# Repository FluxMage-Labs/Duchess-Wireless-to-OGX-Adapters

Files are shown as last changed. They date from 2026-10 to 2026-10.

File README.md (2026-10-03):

# Duchess-Wireless-to-OGX-Adapters
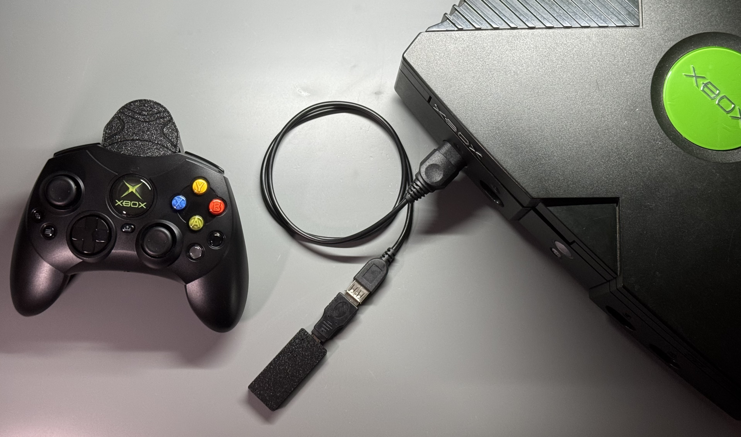
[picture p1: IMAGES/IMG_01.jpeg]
DuchesS Wireless adapters with the original Xbox


These adapters convert the wired-only modern controller, The Hyperkin DuchesS, into a wireless controller for the Original Xbox. Hyperkin made this controller to look and feel like the original S controller from Microsoft. The DuchesS uses hall effect sticks and (thankfully) a detachable USB-C cable. It was designed by Hyperkin to only work on modern Xbox consoles and PC. So, I designed these adapters to use it wirelessly on the OG Xbox. This project is non-destructive, keeping the DuchesS controller in its stock form. The intent is for this to be a fun, DIY, open source project.

The adapters are:

Transmitter – converts USB to Bluetooth, attached to the DuchesS controller.

Receiver – converts Bluetooth to USB, connected to the OG Xbox controller port.

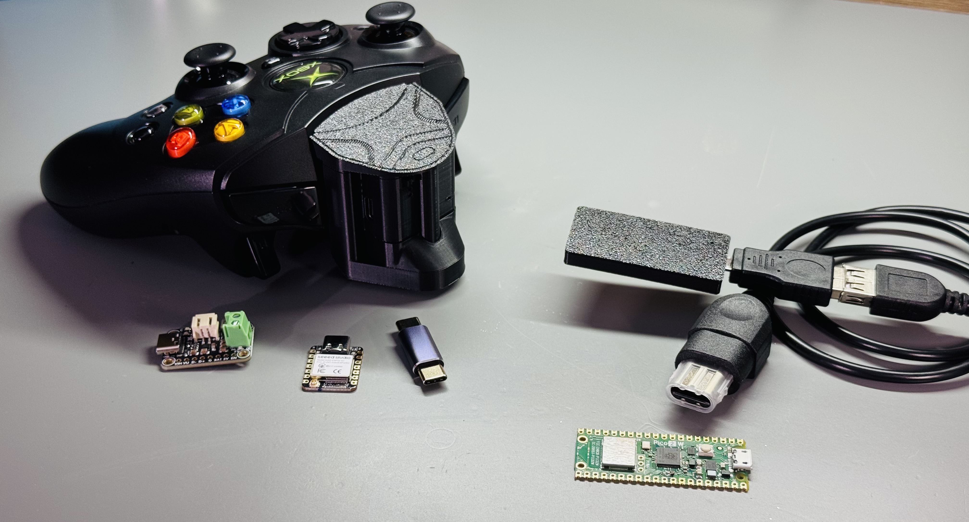
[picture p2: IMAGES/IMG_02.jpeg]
Transmitter and receiver parts


<ins>Please consider the following:</ins>

\*I am sharing this project under the following licenses:

Firmware: GPLv3 License - <https://www.gnu.org/licenses/gpl-3.0.txt>

CAD Designs: CERN-OHL-S-2.0 - <https://ohwr.org/cern_ohl_s_v2.txt>

\*The code for this project was fully vibe-coded with Claude Code using Opus 4.8 during prototyping which produced a working build nearly identical to final v1.0 public release. As of v1.0 the source code was cleaned up and finalized for public release using Opus 5.5 (core functionality was all Opus 4.8, for those who care to know that lol).

\*The enclosures are original designs by me using FreeCAD.

\*As of version 1.0, this project only works properly between the transmitter and receiver.

**These adapters do not currently work with other Bluetooth devices. The transmitter uses Bluetooth LE and thus will not connect to Bluetooth Classic dongles. Also, I can connect the Transmitter to my computer, but the controller inputs don’t work properly. It is coded to work with the OG Xbox receiver only.**

<ins>Below you’ll find:</ins>

1. Video Tutorial
2. Parts List
3. Links to Purchase the parts
4. Wiring Diagram
5. Flashing the Firmware instructions
6. Troubleshooting / Notes

<br>

Please watch the video I made below showing off this project. I explain things in the video that will help anyone considering building this project for themselves.

### [https://youtu.be/EDyjO3ojt0k](https://youtu.be/EDyjO3ojt0k)

<br><br>

Parts require purchase from both Mouser and Amazon. Mouser doesn’t sell everything needed. First look through the parts list, then see links attached below for where to buy each item.

<ins>Parts List:</ins>

- Seeed Studio XIAO ESP32-S3 module – microcontroller board for the Transmitter
- Adafruit Bq25185 (Part # 6106) 5V boost version – Charger and boost circuit for Transmitter
- GCT Slide Switch (MFG Part # SWS065-030V12TSK) – On/Off switch for Transmitter
- 803040 Lipo battery 3.7V 1000mAh with JST PH 2.0mm connector – Transmitter battery
- USB-C Male to Male adapter (32.5mm length) – More of an extender/coupler than an adapter\
  **(The length is important here. Anything less than 32mm won’t fit with the current enclosure).**
- Raspberry Pi Pico 2W – microcontroller board for the Receiver
- USB A Male to USB Micro Male adapter – Converts the Pico’s micro USB to Type A USB
- USB A Female to OG Xbox controller port adapter – Converts USB A to Xbox controller input

\*You’ll also need wires, solder, heat shrink tubing if reversing polarity on the battery (you’ll likely need to do this, the video explains why).

I used 28 AWG stranded wire, but anything similar will work.

\*For the enclosures, I use basic PLA filament.

\*For flashing the firmware, I use a USB Micro to USB-A cable for the Pico, and a USB-C to USB-A cable for the ESP32S3. 

<br>

<ins>-Links to purchase-</ins>

**Mouser project link:** <https://www.mouser.com/en/Tools/Project/Share?AccessID=2832383652>

above link contains the seeed studio ESP32-S3, Adafruit Bq25185, GCT slide switch, Pi Pico 2W.

**Amazon links:** (multiple options in case one goes out of stock, non-affiliate links)

803040 Lipo battery with JST PH 2.0mm connectors -

<https://a.co/d/0bvvcZND>

-or-

<https://a.co/d/07NkPaJw>

USB-C Male to Male adapter 32.5mm total length -

<https://a.co/d/045cscGm>

-or-

<https://a.co/d/06tyFEHX>

USB-A Male to USB Micro Male adapter -

<https://a.co/d/08DQSm7P>

USB-A Female to OG Xbox controller port adapter -

<https://a.co/d/07X1W7fQ>

-or-

<https://a.co/d/00STg7iH>

<br>

<ins>Wiring Diagram:</ins>

(Notice the polarity of the battery had to be switched to match the charger board!)

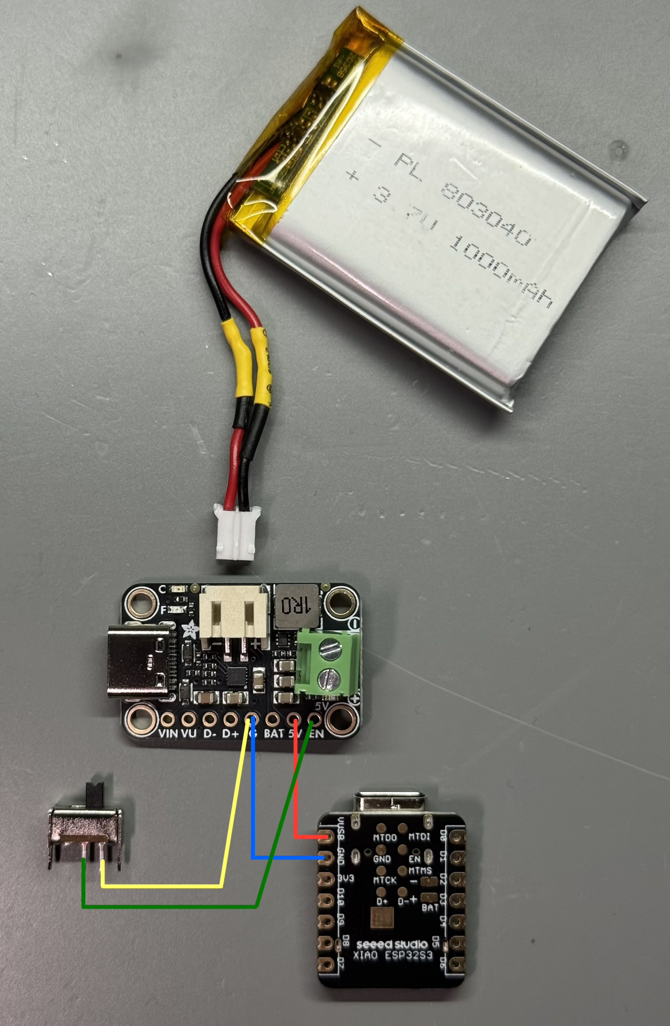
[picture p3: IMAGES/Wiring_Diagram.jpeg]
Wiring diagram


\*Instructions for installing the hardware into the Transmitter enclosure are in the video. 

<br>

<ins>Flashing the Firmware:</ins>

**Transmitter -**

- Download the latest ‘TX_v1.x_merged.bin’ file from the [Releases page](https://github.com/FluxMage-Labs/Duchess-Wireless-to-OGX-Adapters/releases/latest)
- Plug in a USB cable into your computer
- Hold down the “B” (Boot) button on the ESP32S3
- Plug in the other end of the USB cable into the USB-C port of the ESP32S3
- Then release the “B” button on the ESP32S3
- Navigate to the following URL in a Chromium based browser:\
  <https://esptool.spacehuhn.com>
- Click “Connect”
- A Pop-up should appear where you can choose your ESP32S3
- Select it and click “connect” in that pop-up window
- The pop-up window should close
- If a previous firmware already exists, choose “erase” and continue
- Next click the “reset” option on the bottom left of the list on screen\
  (If this is your first time, reset might not do anything, that’s fine. You should see 4 rows listed.)
- Delete rows 2, 3, and 4
- In row 1, delete “1000” and change it to “0”\
  (This starts the binary at 0x0 which is where the merged binary file is designed to start.)
- Click “select” and choose the “...merged.bin” file you downloaded
- Click “Program”
- You should see the Output reads “Done!” and then a message to reset your device (ignore the reset)
- Unplug the ESP32S3 from your computer
- Finished.

**Receiver -**

- Download the latest ‘RX_v1.x_firmware.uf2’ file from the [Releases page](https://github.com/FluxMage-Labs/Duchess-Wireless-to-OGX-Adapters/releases/latest)
- Plug in a USB cable into your computer
- Hold down the BOOTSEL button on the Pi Pico 2W
- Plug in the other end of the USB cable into the USB Micro port of the Pico
- Then release the BOOTSEL button
- Your Pico should show up on your computer similar to a flash drive
- Drag and drop the latest ‘...firmware.uf2’ file into the root directory of the Pico
- The Pico should immediately auto-eject itself from your computer
- Unplug the Pico from your computer
- Finished.

<br>

<ins>Troubleshooting / Notes:</ins>

\* If the transmitter pairs with the receiver, but the Xbox is not receiving controller inputs. **First, make sure the battery is fully charged.** Also, try unplugging the Transmitter from the DuchesS, flipping the orientation of the USB-C to USB-C adapter (from top to bottom) then reconnect the Transmitter to the DuchesS making sure there is a solid tight connection. Then try connecting again. If that doesn’t work, then try flipping the orientation of the adapter (swapped from which side plugs into the controller and Transmitter). We’re trying to change the path that power is flowing through the little adapter to rule that out. **If the DuchesS doesn’t have a good power connection, you can see a faint, slow flicker on the white LED of the DuchesS controller.** If this doesn’t fix the problem, it could potentially be an issue with the solder connections. The DuchesS needs reliable power to function properly.

\* I wouldn’t recommend using less than a 1000mAh battery. Yes, you can avoid having to reverse the polarity on the battery if you buy a battery from Adafruit. I have not tested this project with less than 1000mAh and I’m confident that on a normal controller, you can get away with less capacity, but on this project, for everything to work properly and last long enough through a gaming session or two, you’ll want to keep the battery charged up and not get low enough that it drops out on you.

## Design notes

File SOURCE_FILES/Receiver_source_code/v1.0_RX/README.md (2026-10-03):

# DuchesS Wireless — Receiver (Pi Pico 2 W)

**Version:** v1.0

BLE-to-OG-Xbox bridge firmware for the **Raspberry Pi Pico 2 W**.

Receives wireless BLE gamepad data from the DuchesS Wireless transmitter
(XIAO ESP32S3) and presents it to the **Original Xbox** as a wired
Controller S using the Xbox's XID USB protocol.

This folder is the **receiver** half. The transmitter firmware is in the
[`transmitter/`](../transmitter) folder of this repository. Use the v1.0
transmitter with the v1.0 receiver.

## Signal Chain

```
DuchesS controller (USB/GIP)
    ↓  wired USB
XIAO ESP32S3 (transmitter - BLE gamepad peripheral)
    ↓  wireless BLE
Pi Pico 2 W (THIS FIRMWARE - BLE central + USB XID device)
    ↓  USB via Xbox-to-USB adapter cable
Original Xbox controller port
```

## Hardware Required

| Component | Purpose |
|---|---|
| Raspberry Pi Pico 2 W | Receiver board (BLE + USB) |
| Xbox-to-USB adapter cable | Converts the Xbox controller plug to USB |
| XIAO ESP32S3 + DuchesS | The transmitter side (separate firmware) |
| USB-UART adapter (optional) | For debug serial output on GP0/GP1 |

## Building

Tested with **Pico SDK 2.2.0** and **Arm GNU Toolchain 14.2** (GCC 14.2.1).
The target board (`pico2_w`) is already set in `CMakeLists.txt`.

### Option 1: Linux command line

1. Install the build tools:

   - Arch / EndeavourOS / Manjaro:
     ```bash
     sudo pacman -S --needed base-devel git cmake ninja python arm-none-eabi-gcc arm-none-eabi-newlib
     ```
   - Debian / Ubuntu / Raspberry Pi OS:
     ```bash
     sudo apt install build-essential git cmake ninja-build python3 gcc-arm-none-eabi libnewlib-arm-none-eabi libstdc++-arm-none-eabi-newlib
     ```

2. Get the Pico SDK 2.2.0 **with its submodules** (BTstack, the CYW43
   wireless driver and TinyUSB live in submodules — the build fails
   without them):
   ```bash
   git clone -b 2.2.0 https://github.com/raspberrypi/pico-sdk.git ~/pico-sdk
   cd ~/pico-sdk
   git submodule update --init
   ```

3. Build, from this `receiver` folder:
   ```bash
   export PICO_SDK_PATH=~/pico-sdk
   cmake -B build -G Ninja
   cmake --build build
   ```
   Instead of the `export`, you can pass the path directly:
   `cmake -B build -G Ninja -DPICO_SDK_PATH=$HOME/pico-sdk`

   The first configure downloads and builds `picotool` (a Raspberry Pi
   helper tool), so it needs an internet connection and takes a little
   longer.

4. The firmware is `build/duchess_receiver.uf2`.

### Option 2: VS Code with the Raspberry Pi Pico extension (Windows, macOS, Linux)

1. Install the **Raspberry Pi Pico** extension. It downloads the SDK,
   toolchain, CMake and Ninja for you.
2. Use **Import Project** on this `receiver` folder and choose **SDK 2.2.0**.
3. Click **Compile**. The output is `build/duchess_receiver.uf2`.

## Flashing

The Pico 2 W uses drag-and-drop flashing — no programmer needed.

1. **Hold the BOOTSEL button** on the Pico 2 W
2. While holding it, **plug the Pico into your computer via micro-USB**
3. Release BOOTSEL — the Pico appears as a USB drive named **RP2350**
4. **Copy `duchess_receiver.uf2` onto that drive**
5. The Pico reboots automatically and starts running the firmware

Pre-built `.uf2` files are attached to the project's GitHub Releases.

## Usage

### First Time Setup

1. Flash the receiver firmware onto the Pico 2 W (see above)
2. Flash the transmitter firmware onto the XIAO ESP32S3 (see `transmitter/`)
3. Power on the XIAO with the DuchesS controller connected
4. Connect the Pico 2 W to the OG Xbox via the Xbox-to-USB adapter cable
5. The Pico scans for and connects to the transmitter automatically
6. Once connected, the Xbox sees a controller

### Normal Operation

1. Plug the Pico 2 W into the Xbox (via the adapter cable) — it immediately
   appears as a Controller S to the Xbox
2. Power on the XIAO transmitter with the DuchesS controller
3. The Pico auto-connects via BLE within a few seconds
4. Play!

### Re-pairing / Troubleshooting BLE

Pairing is automatic. Both the receiver and the transmitter clear their
stored BLE pairing data every time they power up, so if the connection ever
gets stuck (for example after reflashing either side), **power-cycle both
the transmitter and the receiver** and they will pair again from scratch.

If everything lights up but no inputs reach the Xbox, check the
transmitter's battery first — see the Troubleshooting section in the
transmitter README.

## LED Indicators

| Pattern | Meaning |
|---|---|
| Fast blink (5 Hz) | Scanning for the transmitter |
| Slow blink (1 Hz) | BLE connected, Xbox USB not yet active |
| Solid ON | Both BLE and Xbox USB active — ready to play |

## Button Mapping (DuchesS → OG Xbox)

| DuchesS | OG Xbox |
|---|---|
| A | A (analog 0xFF) |
| B | B (analog 0xFF) |
| X | X (analog 0xFF) |
| Y | Y (analog 0xFF) |
| White / LB (Left Bumper) | White (analog 0xFF) |
| Black / RB (Right Bumper) | Black (analog 0xFF) |
| Start / Menu | Start |
| Back / View | Back |
| Left Stick Click | Left Stick Click |
| Right Stick Click | Right Stick Click |
| D-Pad | D-Pad |
| Left Stick | Left Stick |
| Right Stick | Right Stick |
| Left Trigger | Left Trigger (scaled 0-255) |
| Right Trigger | Right Trigger (scaled 0-255) |

Note: The OG Xbox Controller S has analog (pressure-sensitive) face
buttons. The DuchesS face buttons are digital, so they send either 0x00
(off) or 0xFF (fully pressed).

## Technical Details

### XID Protocol

The OG Xbox uses a USB protocol called XID (Xbox Input Devices):
- Interface class `0x58` ('X'), subclass `0x42` ('B')
- Not standard USB HID — no HID descriptors
- Vendor-specific control transfers for device identification
- 20-byte input reports, 6-byte output reports (rumble)
- Identifies as VID `0x045E` / PID `0x0289` (Controller S), which the
  Xbox requires in order to accept the controller
- USB 1.1 Full Speed, 4 ms polling interval

### BLE Connection

The receiver acts as a BLE Central (client):
- Scans for a device named exactly "DuchesS Wireless"
- Connects with Just Works pairing + bonding
- Discovers the HID service (UUID 0x1812)
- Subscribes to input report notifications (15-byte reports: buttons,
  six axes, then the hat switch as the last byte)
- Auto-reconnects on disconnection

The transmitter requests a 7.5–8.75 ms BLE connection interval for low
latency.

### Latency Budget (estimated)

| Stage | Latency |
|---|---|
| DuchesS → XIAO GIP read | ~1-2 ms |
| XIAO BLE notification queue | ~0.5 ms |
| BLE connection interval | 0-8.75 ms |
| BLE air time + processing | ~0.5-1 ms |
| Pico mapping + XID buffer | ~0.1 ms |
| Xbox USB poll | 0-4 ms (avg 2 ms) |
| **Total end-to-end** | **~5-15 ms typical** |

## Project Structure

```
receiver/
├── CMakeLists.txt              # Build configuration
├── pico_sdk_import.cmake       # Locates the Pico SDK (from Raspberry Pi)
├── README.md                   # This file
├── LICENSE-EXCEPTION.md        # GPLv3 section 7 additional permission
└── src/
    ├── btstack_config.h        # BTstack configuration
    ├── tusb_config.h           # TinyUSB configuration
    ├── gamepad_state.h/.c      # Shared gamepad state
    ├── ble_hid_client.h/.c     # BLE Central HID client
    ├── xid_device.h/.c         # OG Xbox XID USB device
    └── main.c                  # Entry point, ties everything together
```

## Debug Output

Connect a USB-UART adapter to the Pico's UART0 pins:
- **GP0** (Pin 1) = TX → connect to adapter's RX
- **GP1** (Pin 2) = RX → connect to adapter's TX (optional)
- **GND** → connect to adapter's GND

Open a serial terminal at **115200 baud** to see debug output.

## License

GNU GPL v3 or later — see the LICENSE file at the repository root —
**with an additional permission** under GPLv3 section 7 that allows
combining this firmware with BTstack and the CYW43 wireless driver from the
Raspberry Pi Pico SDK. See [LICENSE-EXCEPTION.md](LICENSE-EXCEPTION.md).
Each source file carries an `SPDX-License-Identifier: GPL-3.0-or-later`
header and a pointer to that exception.

## Third-party components

None of these are included in this folder; they come with the Pico SDK
when you build.

- **Raspberry Pi Pico SDK** — BSD-3-Clause.
  `pico_sdk_import.cmake` in this folder is Raspberry Pi's standard helper
  file, included unmodified with its BSD-3-Clause notice.
- **TinyUSB** — MIT License.
- **BTstack** by BlueKitchen GmbH — BlueKitchen license (non-commercial),
  plus Raspberry Pi's license for use on Raspberry Pi hardware.
- **cyw43-driver** by George Robotics (with the Infineon CYW43439 firmware)
  — George Robotics license (non-commercial) in the version used by SDK
  2.2.0, plus Raspberry Pi's license for use on Raspberry Pi hardware.

## Credits

- [xboxdevwiki.net](https://xboxdevwiki.net/Xbox_Input_Devices) — XID
  protocol documentation
- [OGX-Mini](https://github.com/wiredopposite/OGX-Mini) — consulted as a
  reference for XID on RP2040/RP2350 (no code from it is used here)
- [BTstack](https://github.com/bluekitchen/btstack),
  [TinyUSB](https://github.com/hathach/tinyusb),
  [Pico SDK](https://github.com/raspberrypi/pico-sdk)

## Disclaimer

This is an independent, non-commercial hobby project. It is not affiliated
with, endorsed by, or sponsored by Microsoft, Hyperkin, or Raspberry Pi.
"Xbox" is a trademark of Microsoft Corporation; "Hyperkin" and "DuchesS"
are trademarks of their respective owner. These names, and the Controller S
USB identifiers the Xbox requires, are used only for compatibility and to
describe what hardware this project works with.

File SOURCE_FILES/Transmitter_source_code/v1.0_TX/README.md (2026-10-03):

# DuchesS Wireless — Transmitter (XIAO ESP32S3)

**Version:** v1.0

Firmware that converts a wired Hyperkin DuchesS USB controller into a
wireless controller for the Original Xbox.

**Signal chain:**

```
DuchesS (USB/GIP) -> XIAO ESP32S3 (this firmware) -> BLE -> Pi Pico 2 W receiver -> OG Xbox
```

This folder is the **transmitter** half. The Pi Pico 2 W **receiver**
firmware is in the [`receiver/`](../receiver) folder of this repository.

## Hardware

- Seeed Studio XIAO ESP32S3
- Hyperkin DuchesS controller, connected via USB-C OTG adapter
- 1-cell LiPo battery + charge/boost board supplying 5V to the XIAO's
  VUSB pin (the XIAO's own USB-C port is occupied by the controller in
  host mode). Reference board: **Adafruit bq25185 USB/DC/Solar Charger
  with 5V Boost** (Adafruit #6106) — battery on the JST port, board
  "+" (5V) output to XIAO VUSB, grounds common.
- Optional: USB-UART adapter on GPIO43(TX)/GPIO44(RX), 115200 baud,
  for debug output

> **Boost converter startup note (bq25185 board):** its TPS61023 boost
> converter can stall into loads that instantly draw more than ~200mA
> at power-up. The ESP32-S3 starts below that and only ramps up when
> the radio and USB host come alive moments later, so normal operation
> is fine — but if you add extra hardware to the 5V rail, keep its
> inrush in mind.

## Low-battery indicator (optional, recommended)

A weak LiPo can light every status LED in the system while still
sagging under the ESP32-S3's radio transmit spikes and the USB host
port's load — the result is "all lights on, but no controller inputs
reach the Xbox." The firmware supports two independent detection
methods. Wire either (or both); each is safely inactive when left
unconnected.

### Method A — battery voltage sense (works with the bq25185 board)

The bq25185 board exposes the raw battery voltage on its bottom-edge
**BAT** pad. Feed it to the XIAO through a divider:

```
BAT pad ──[100kΩ]──●──[100kΩ]── GND
                   │
              XIAO A0 (D0)
```

The divider halves the battery voltage into the ADC's range and draws
only ~21µA. The firmware auto-detects it: after a few seconds of
plausible readings it arms, then reports the live voltage on the debug
UART and warns below 3.30V (recovering above 3.60V). If nothing is
wired to A0, the method never arms and nothing changes.

### Method B — dedicated low-battery pin (LBO-style boards)

If your charge/boost board instead has a low-battery output (often
labeled **LBO**, **LB**, or **LOWBATT** — pulls LOW when the battery is
nearly empty), connect it to the XIAO's **D1 (GPIO2)**. Internal
pull-up; leave unconnected if unused.

## LED status codes

| Pattern | Meaning |
|---|---|
| Triple-blink burst | **LOW BATTERY — charge before use!** |
| Fast blink (5/sec) | Waiting for the DuchesS controller (USB) |
| Slow blink (1/sec) | Controller OK, waiting for the receiver (BLE)  |
| Solid on | Fully connected and operational |

## Troubleshooting

**Everything lights up, but no inputs reach the Xbox.**
Almost always a **weak battery**. A partially charged LiPo has enough
power to light every LED — the charger board, the ESP32, the
controller's white light, even to trigger the receiver's connect
light — while still sagging under load. LEDs prove almost nothing
about available power.

1. Fully charge the battery, or power the XIAO's 5V input from a bench
   supply / USB source to rule power out.
2. Wire the low-battery indicator (above) and the triple-blink pattern
   will tell you directly.

**Controller inputs feel dead after reflashing.**
Power-cycle both the transmitter and the receiver. Both sides clear
their BLE bonds at boot and re-pair automatically.

**Serial port won't connect when flashing (Linux).**
Your user needs permission for the serial device. On Arch-based
distros: `sudo usermod -aG uucp $USER`, then log out and back in.

## Building

See [BUILDING.md](BUILDING.md) for the full build, merge, and flash
procedure, including the exact pinned library versions this firmware
requires.

## License

GNU GPL v3 or later — see the LICENSE file at the repository root —
**with an additional permission** under GPLv3 section 7 that allows
linking with Espressif's precompiled (binary-only) ESP-IDF libraries.
See [LICENSE-EXCEPTION.md](LICENSE-EXCEPTION.md). Each source file
written for this project carries an
`SPDX-License-Identifier: GPL-3.0-or-later` header and a pointer to
that exception.

## Third-party code

- **ESP32-BLE-Gamepad** by lemmingDev — MIT License, vendored in
  [`lib/ESP32-BLE-Gamepad`](lib/ESP32-BLE-Gamepad) with its original
  [`license.txt`](lib/ESP32-BLE-Gamepad/license.txt).
  Source: <https://github.com/lemmingDev/ESP32-BLE-Gamepad>, upstream
  commit `33a3dee` (library version 0.7.4).
  **Modified:** `BleConnectionStatus.cpp` — one line added to
  `onConnect()` (`this->connected = true;`) so the connection is reported
  as soon as the link is up, rather than only after authentication.
- **NimBLE-Arduino** by h2zero — Apache License 2.0. Not included in this
  repository; PlatformIO downloads the pinned version (2.3.9) at build
  time.

## Disclaimer

This is an independent, non-commercial hobby project. It is not
affiliated with, endorsed by, or sponsored by Hyperkin or Microsoft.
"Hyperkin" and "DuchesS" are trademarks of their respective owner, and
"Xbox" is a trademark of Microsoft Corporation. These names are used
only to describe what hardware this project works with.

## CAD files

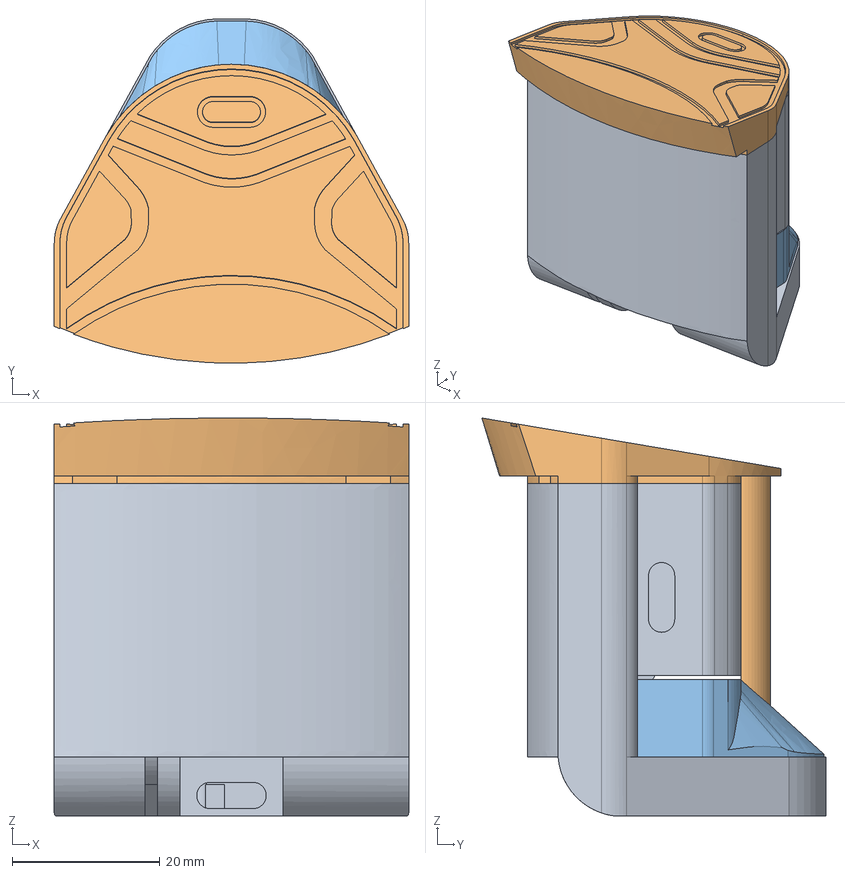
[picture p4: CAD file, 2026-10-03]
SOURCE_FILES/FreeCAD_files/v1.0_Transmitter.FCStd
48.0 x 46.6 x 53.9 mm
Main Body
Top Lid
Bottom Lid

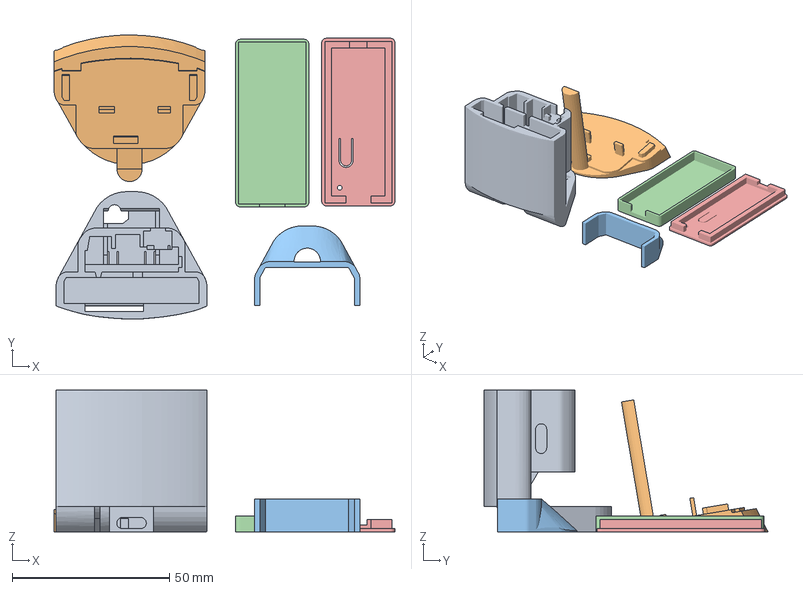
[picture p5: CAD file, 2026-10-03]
v1.0_Enclosures.3mf
108.3 x 90.3 x 45.0 mm

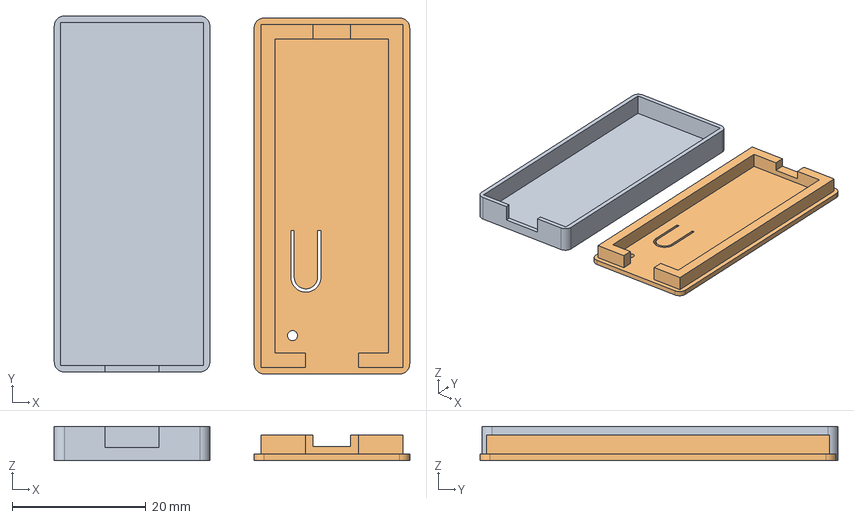
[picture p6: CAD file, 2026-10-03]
SOURCE_FILES/FreeCAD_files/v1.0_Receiver.FCStd
53.2 x 53.6 x 5.10 mm
Lid

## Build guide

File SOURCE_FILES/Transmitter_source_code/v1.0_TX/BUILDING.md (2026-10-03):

# Building the DuchesS Wireless Transmitter (XIAO ESP32S3)

## Requirements
- PlatformIO Core (CLI) 6.x — `pipx install platformio`
- Internet access on first build (downloads espressif32 platform + toolchain)

## Build

From this folder (the one containing `platformio.ini`):

```bash
pio run
```

Artifacts land in `.pio/build/seeed_xiao_esp32s3/`:
`bootloader.bin`, `partitions.bin`, `firmware.bin`.

> If you previously built with different library versions, do a clean
> build first: `rm -rf .pio && pio run`

## Create the single-file merged image (for web flashers)

```bash
cd .pio/build/seeed_xiao_esp32s3

pio pkg exec -p tool-esptoolpy -- esptool.py --chip esp32s3 merge_bin \
  -o merged.bin \
  --flash_mode dio --flash_freq 80m --flash_size 8MB \
  0x0 bootloader.bin \
  0x8000 partitions.bin \
  0xe000 ~/.platformio/packages/framework-arduinoespressif32/tools/partitions/boot_app0.bin \
  0x10000 firmware.bin
```

> **Note:** the `boot_app0.bin` path above assumes PlatformIO's default
> location on Linux/macOS. On Windows use
> `%USERPROFILE%\.platformio\packages\framework-arduinoespressif32\tools\partitions\boot_app0.bin`,
> or wherever your PlatformIO core directory is (`pio system info` shows it).

`merged.bin` flashes as a single file at offset `0x0`.

## Flash (PlatformIO direct)

Hold BOOT on the XIAO, plug it into your computer, release BOOT, then:

```bash
pio run -t upload
```

## Flash (web flasher method)

1. Hold the BOOT button on the XIAO ESP32S3
2. Plug in the USB-C cable, then release BOOT
3. Open a Web-Serial flasher (e.g. esptool.spacehuhn.com) in a
   Chromium-based browser and Connect
4. Single entry: offset `0x0`, file `merged.bin`
5. Erase (recommended), then Program
6. Unplug/replug the XIAO to boot the new firmware

Linux note: your user must be able to open the serial port
(`uucp` group on Arch: `sudo usermod -aG uucp $USER`, then re-login).

## Before publishing binaries

Verify no local paths leaked into the artifacts:

```bash
strings merged.bin | grep -iE '/home/|users' && echo "LEAK FOUND" || echo "clean"
```

## Version pins — do not bump casually

| Component | Version | Why pinned |
|---|---|---|
| espressif32 platform | 6.9.0 | Matches the verified-working release build |
| NimBLE-Arduino | 2.3.9 | Exact version of the verified-working build (verified byte-identical to the official GitHub 2.3.9 tag, so the registry pin is safe). |
| ESP32-BLE-Gamepad | vendored in `lib/` | The registry's "0.7.4" changed content over time WITHOUT a version bump - connection-status semantics and the HID report descriptor were altered, silently breaking pairing/input flow. The exact verified-working source (including a local fix in BleConnectionStatus.cpp) is committed in `lib/ESP32-BLE-Gamepad` and used automatically. Never replace it with a registry copy. |

Do not add ESP32-BLE-Gamepad back to `lib_deps` - the local `lib/` copy
must be the one that builds.

## After flashing: if it doesn't work

See the Troubleshooting section in [README.md](README.md) first —
especially the weak-battery failure mode, which mimics several other
problems. Always do first functional tests on solid power (bench supply
or full battery), never on a partially charged LiPo.

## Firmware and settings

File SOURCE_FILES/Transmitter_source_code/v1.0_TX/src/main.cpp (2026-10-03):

// SPDX-License-Identifier: GPL-3.0-or-later
// Copyright (C) 2026 DuchesS Wireless contributors
// Additional permission under GNU GPL version 3 section 7: see LICENSE-EXCEPTION.md

/*
 * main.cpp - DuchesS Wireless Transmitter
 *
 * XIAO ESP32S3 firmware: reads DuchesS controller via USB Host (GIP)
 * and transmits as BLE HID gamepad to the Pi Pico 2 W receiver.
 *
 * Signal chain:
 *   DuchesS (USB/GIP) -> XIAO ESP32S3 (this) -> BLE -> Pico 2 W -> OG Xbox
 *
 * Hardware:
 *   - Single USB-C port: used for flashing (from PC) then USB Host (controller)
 *   - LED: GPIO21, active LOW
 *   - Debug UART: GPIO43(TX), GPIO44(RX), 115200 baud
 *
 * OPTIONAL LOW-BATTERY DETECTION (two methods, wire either or both;
 * both are safely inactive when left unconnected):
 *
 *   Method A - Analog battery sense on A0 (GPIO1):
 *     For charge/boost boards that expose the raw battery voltage,
 *     e.g. the Adafruit bq25185 5V Boost board's bottom-edge BAT pad.
 *     Wire: BAT pad -> 100k resistor -> A0 -> 100k resistor -> GND.
 *     The divider halves the battery voltage into the ADC's range.
 *     The firmware auto-detects the divider: it arms only after
 *     several consecutive readings in the plausible LiPo range, so an
 *     unwired (floating) pin can never trigger a false warning.
 *
 *   Method B - Digital low-battery input on D1 (GPIO2), active LOW:
 *     For charge/boost boards with a dedicated low-battery output
 *     (often labeled LBO, LB, or LOWBATT, e.g. Adafruit PowerBoost).
 *     The internal pull-up keeps this inactive when unconnected.
 *
 * LED status codes (LED is active LOW):
 *   Triple-blink burst = LOW BATTERY - charge before use!
 *   Fast blink (5/sec) = waiting for USB controller
 *   Slow blink (1/sec) = USB OK, waiting for BLE receiver
 *   Solid ON           = USB + BLE connected, fully operational
 *
 * WHY THE LOW-BATTERY INDICATOR EXISTS:
 *   A weak LiPo can light every status LED in the system (charger,
 *   ESP32, controller, even trigger the receiver's connect light)
 *   while still sagging under the ESP32-S3's radio transmit spikes
 *   and the USB host port's supply load - the result is "all lights
 *   on, but no controller inputs reach the Xbox." The dedicated
 *   triple-blink pattern makes that failure unmistakable.
 */

#include <Arduino.h>
#include "gamepad_state.h"
#include "usb_host_xbox.h"
#include "ble_output.h"

// Debug UART on GPIO43(TX) / GPIO44(RX) since USB port becomes Host
#define DEBUG_TX_PIN 43
#define DEBUG_RX_PIN 44
HardwareSerial DebugSerial(1);

static gamepad_state_t gamepad;

// XIAO ESP32S3 LED: GPIO21, active LOW (LOW = on, HIGH = off)
#define LED_PIN 21

// ---------------------------------------------------------------------------
// Low-battery detection configuration
// ---------------------------------------------------------------------------

// Method A: analog battery sense (XIAO A0). Battery voltage through a
// 100k/100k divider, so measured mV * 2 = battery mV.
#define BATT_SENSE_PIN        1      // GPIO1 = XIAO A0/D0
#define BATT_DIVIDER_RATIO    2      // 100k : 100k divider halves voltage
#define BATT_LOW_MV           3300   // warn below 3.30V
#define BATT_RECOVER_MV       3600   // clear warning above 3.60V
// Plausible single-cell LiPo range; readings outside this mean the
// divider is not wired (floating pin) and the method stays disarmed.
#define BATT_PLAUSIBLE_MIN_MV 2700
#define BATT_PLAUSIBLE_MAX_MV 4400
#define BATT_ARM_SAMPLES      5      // consecutive plausible reads to arm
#define BATT_SAMPLE_MS        1000   // sample interval

// Method B: digital low-battery input (XIAO D1). Active LOW, pull-up.
#define LOW_BATT_PIN     2
#define LOW_BATT_ON_MS   500         // continuously LOW this long -> warn
#define LOW_BATT_OFF_MS  2000        // continuously HIGH this long -> clear

// ---------------------------------------------------------------------------

static uint32_t last_status_print = 0;
static uint32_t last_ble_send     = 0;
static uint32_t last_led_toggle   = 0;
static bool     led_state         = false;

// Method A state
static bool     batt_sense_armed   = false;
static uint8_t  batt_arm_count     = 0;
static bool     batt_analog_low    = false;
static uint32_t batt_last_sample   = 0;
static uint32_t batt_mv            = 0;   // last measured battery voltage

// Method B state
static bool     lbo_active     = false;
static uint32_t lbo_last_high  = 0;
static uint32_t lbo_last_low   = 0;

void setup() {
    DebugSerial.begin(115200, SERIAL_8N1, DEBUG_RX_PIN, DEBUG_TX_PIN);
    delay(500);

    DebugSerial.println("============================================");
    DebugSerial.println("  DuchesS Wireless Transmitter");
    DebugSerial.println("  XIAO ESP32S3 -> BLE -> Pico 2 W -> Xbox");
    DebugSerial.println("  Firmware v1.0");
    DebugSerial.println("============================================");
    DebugSerial.println();

    // LED off initially
    pinMode(LED_PIN, OUTPUT);
    digitalWrite(LED_PIN, HIGH);

    // Method B input: pull-up keeps it inactive when unconnected
    pinMode(LOW_BATT_PIN, INPUT_PULLUP);
    uint32_t boot_ms = millis();
    lbo_last_high = boot_ms;
    lbo_last_low  = boot_ms;

    // Method A input: plain analog pin; auto-arms only if a divider
    // feeding plausible LiPo voltages is detected.
    analogReadResolution(12);

    gamepad_state_reset(&gamepad);

    // Start BLE first (begins advertising immediately)
    ble_output_init();

    // Then start USB Host for the DuchesS controller
    usb_host_xbox_init(&gamepad);

    DebugSerial.println("[MAIN] Setup complete!");
    DebugSerial.println("[MAIN] Connect DuchesS via USB-C OTG adapter");
    DebugSerial.println("[MAIN] Pico 2 W receiver auto-connects via BLE");
    DebugSerial.println();
}

// ---------------------------------------------------------------------------
// Low-battery detection task (both methods)
// ---------------------------------------------------------------------------
static void low_battery_task(uint32_t now) {
    // ---- Method A: analog battery sense ----
    if (now - batt_last_sample >= BATT_SAMPLE_MS) {
        batt_last_sample = now;

        // Calibrated millivolts at the pin; x2 for the 100k/100k divider
        uint32_t pin_mv = analogReadMilliVolts(BATT_SENSE_PIN);
        uint32_t measured_mv = pin_mv * BATT_DIVIDER_RATIO;

        bool plausible = (measured_mv >= BATT_PLAUSIBLE_MIN_MV &&
                          measured_mv <= BATT_PLAUSIBLE_MAX_MV);

        if (!batt_sense_armed) {
            // Require several consecutive plausible readings before
            // trusting the input - a floating pin wanders and will
            // not hold a steady LiPo-range value.
            if (plausible) {
                if (++batt_arm_count >= BATT_ARM_SAMPLES) {
                    batt_sense_armed = true;
                    batt_mv = measured_mv;
                    DebugSerial.printf("[BATT] Battery sense detected on A0 (%lumV)\n",
                                       (unsigned long)measured_mv);
                }
            } else {
                batt_arm_count = 0;
            }
        } else {
            batt_mv = measured_mv;
            if (!batt_analog_low && measured_mv < BATT_LOW_MV) {
                batt_analog_low = true;
                DebugSerial.printf("[BATT] LOW BATTERY (%lumV) - charge before use!\n",
                                   (unsigned long)measured_mv);
            } else if (batt_analog_low && measured_mv > BATT_RECOVER_MV) {
                batt_analog_low = false;
                DebugSerial.printf("[BATT] Battery recovered (%lumV)\n",
                                   (unsigned long)measured_mv);
            }
        }
    }

    // ---- Method B: digital LBO input (active LOW, hysteresis latch) ----
    if (digitalRead(LOW_BATT_PIN) == HIGH) {
        lbo_last_high = now;
    } else {
        lbo_last_low = now;
    }

    if (!lbo_active && (now - lbo_last_high >= LOW_BATT_ON_MS)) {
        lbo_active = true;
        DebugSerial.println("[BATT] LOW BATTERY (LBO pin) - charge before use!");
    } else if (lbo_active && (now - lbo_last_low >= LOW_BATT_OFF_MS)) {
        lbo_active = false;
        DebugSerial.println("[BATT] Battery level OK again (LBO pin)");
    }
}

static inline bool low_battery_active(void) {
    return batt_analog_low || lbo_active;
}

void loop() {
    uint32_t now = millis();

    // Process USB host events
    usb_host_xbox_task();

    // Send BLE reports at ~250Hz when new data arrives
    if (gamepad.updated && (now - last_ble_send >= 4)) {
        if (ble_output_connected()) {
            ble_output_send(&gamepad);
        }
        gamepad.updated = false;
        last_ble_send = now;
    }

    // Low-battery detection (both optional methods)
    low_battery_task(now);

    // LED indicator (active LOW: LOW = on, HIGH = off)
    //   Triple-blink burst = LOW BATTERY (overrides everything)
    //   Fast blink         = no USB controller
    //   Slow blink         = USB ok, no BLE connection
    //   Solid ON           = both USB and BLE connected
    if (low_battery_active()) {
        // Triple-blink burst: 3 short flashes, then a pause (1.3s cycle)
        uint32_t phase = now % 1300;
        bool on = (phase < 100) ||
                  (phase >= 200 && phase < 300) ||
                  (phase >= 400 && phase < 500);
        if (on != led_state) {
            led_state = on;
            digitalWrite(LED_PIN, on ? LOW : HIGH);
        }
        last_led_toggle = now;
    } else {
        bool usb_ok = usb_host_xbox_connected();
        bool ble_ok = ble_output_connected();

        if (usb_ok && ble_ok) {
            if (!led_state) {
                led_state = true;
                digitalWrite(LED_PIN, LOW);
            }
        } else if (usb_ok) {
            if (now - last_led_toggle >= 1000) {
                led_state = !led_state;
                digitalWrite(LED_PIN, led_state ? LOW : HIGH);
                last_led_toggle = now;
            }
        } else {
            if (now - last_led_toggle >= 200) {
                led_state = !led_state;
                digitalWrite(LED_PIN, led_state ? LOW : HIGH);
                last_led_toggle = now;
            }
        }
    }

    // Status print every 5 seconds
    if (now - last_status_print >= 5000) {
        last_status_print = now;
        DebugSerial.printf("[STATUS] USB:%s BLE:%s",
                   usb_host_xbox_connected() ? "OK" : "wait",
                   ble_output_connected() ? "CONNECTED" : "advertising");
        if (batt_sense_armed) {
            DebugSerial.printf(" BATT:%lumV(%s)",
                       (unsigned long)batt_mv,
                       low_battery_active() ? "LOW" : "ok");
        } else {
            DebugSerial.printf(" BATT:%s", low_battery_active() ? "LOW" : "ok");
        }
        if (gamepad.connected) {
            DebugSerial.printf(" LX=%d LY=%d LT=%d RT=%d",
                       gamepad.left_stick_x, gamepad.left_stick_y,
                       gamepad.left_trigger, gamepad.right_trigger);
        }
        DebugSerial.println();
    }

    delay(1);
}

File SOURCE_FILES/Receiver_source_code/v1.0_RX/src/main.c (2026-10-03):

// SPDX-License-Identifier: GPL-3.0-or-later
// Copyright (C) 2026 DuchesS Wireless contributors
// Additional permission under GNU GPL version 3 section 7: see LICENSE-EXCEPTION.md

/*
 * main.c
 *
 * DuchesS Wireless Receiver - Pi Pico 2 W
 *
 * Signal chain:
 *   DuchesS (USB/GIP) -> XIAO ESP32S3 (BLE gamepad) -> [wireless]
 *     -> Pico 2 W (this firmware: BLE client + USB XID device) -> OG Xbox
 *
 * Architecture:
 *   - TinyUSB initializes FIRST so the Xbox sees a controller at boot
 *   - BTStack initializes second and scans for the XIAO transmitter
 *   - Until BLE connects, the XID device sends neutral/idle reports
 *   - Once BLE connects, incoming gamepad data is translated to XID format
 *
 * Hardware:
 *   - Pico 2 W micro-USB port -> Xbox-to-USB adapter cable -> OG Xbox
 *   - Re-pairing is automatic: BLE bonds are cleared at every power-up
 *   - Onboard LED (via CYW43): indicates connection status
 *   - UART0 (GP0=TX, GP1=RX): debug serial output at 115200 baud
 *
 * LED patterns:
 *   Fast blink  = scanning for BLE gamepad
 *   Slow blink  = BLE connected, waiting for Xbox USB
 *   Solid ON    = both BLE and USB active
 */

#include <stdio.h>
#include <string.h>
#include "pico/stdlib.h"
#include "pico/cyw43_arch.h"
#include "hardware/gpio.h"

#include "tusb.h"
#include "gamepad_state.h"
#include "ble_hid_client.h"
#include "xid_device.h"

// ---------------------------------------------------------------------------
// TinyUSB device callbacks — track USB enumeration state
// ---------------------------------------------------------------------------
void tud_mount_cb(void) {
    printf("[USB] *** MOUNTED — host sent SET_CONFIGURATION ***\n");
    fflush(stdout);
}

void tud_umount_cb(void) {
    printf("[USB] *** UNMOUNTED ***\n");
    fflush(stdout);
}

void tud_suspend_cb(bool remote_wakeup_en) {
    (void)remote_wakeup_en;
    printf("[USB] *** SUSPENDED ***\n");
    fflush(stdout);
}

void tud_resume_cb(void) {
    printf("[USB] *** RESUMED ***\n");
    fflush(stdout);
}

// ---------------------------------------------------------------------------
// Globals
// ---------------------------------------------------------------------------
static gamepad_state_t gamepad;

// LED state
static uint32_t last_led_toggle = 0;
static bool led_on = false;

// Status printing
static uint32_t last_status_print = 0;

// ---------------------------------------------------------------------------
// Main
// ---------------------------------------------------------------------------
int main(void) {
    // Initialize stdio (UART0 on GP0/GP1)
    stdio_init_all();
    sleep_ms(1000);  // Wait for UART to settle

    printf("\n");
    printf("=============================================\n");
    printf("  DuchesS Wireless Receiver\n");
    printf("  Pi Pico 2 W - BLE to OG Xbox Bridge\n");
    printf("  Firmware v1.0\n");
    printf("=============================================\n\n");

    // Initialize gamepad state to neutral
    gamepad_state_reset(&gamepad);

    // --- Step 1: Initialize USB XID device FIRST ---
    // This must happen before BLE so the Xbox can enumerate the
    // controller immediately at boot. The XID device sends idle
    // reports (sticks centered, no buttons) until BLE connects.
    printf("[MAIN] Step 1: Initializing USB XID device...\n");
    xid_device_init(&gamepad);

    // --- Step 2: Initialize CYW43 (WiFi/BLE chip) ---
    printf("[MAIN] Step 2: Initializing CYW43 wireless...\n");
    if (cyw43_arch_init()) {
        printf("[MAIN] ERROR: CYW43 init failed!\n");
        while (1) { tight_loop_contents(); }
    }
    printf("[MAIN] CYW43 initialized OK\n");

    // --- Step 3: Initialize BLE HID client ---
    printf("[MAIN] Step 3: Initializing BLE HID client...\n");
    ble_hid_client_init(&gamepad);

    printf("\n[MAIN] Setup complete!\n");
    printf("[MAIN] USB XID device active (Xbox should see a controller)\n");
    printf("[MAIN] BLE scanning for 'DuchesS Wireless' transmitter...\n");
    printf("\n");

    // ---------------------------------------------------------------------------
    // Main loop
    // ---------------------------------------------------------------------------
    printf("[MAIN] Entering main loop...\n");
    fflush(stdout);

    uint32_t last_xid_send = 0;

    while (1) {
        uint32_t now = to_ms_since_boot(get_absolute_time());

        // --- TinyUSB task ---
        tud_task();

        // --- Update XID report data when BLE data arrives ---
        if (gamepad.updated) {
            xid_device_update();
            gamepad.updated = false;
        }

        // --- Send XID report every 4ms (match Xbox polling interval) ---
        // The Xbox polls the interrupt IN endpoint continuously.
        // We must keep it supplied with data or the Xbox thinks
        // the controller is unresponsive.
        if (now - last_xid_send >= 4) {
            last_xid_send = now;
            xid_device_send_report();
        }

        // --- LED patterns based on actual state ---
        {
            bool ble_ok = ble_hid_client_connected();
            bool usb_ok = tud_ready();

            if (ble_ok && usb_ok) {
                // Solid ON = both active
                if (!led_on) {
                    led_on = true;
                    cyw43_arch_gpio_put(CYW43_WL_GPIO_LED_PIN, true);
                }
            } else if (ble_ok) {
                // Slow blink = BLE connected, no USB
                if (now - last_led_toggle >= 1000) {
                    led_on = !led_on;
                    cyw43_arch_gpio_put(CYW43_WL_GPIO_LED_PIN, led_on);
                    last_led_toggle = now;
                }
            } else {
                // Fast blink = scanning
                if (now - last_led_toggle >= 200) {
                    led_on = !led_on;
                    cyw43_arch_gpio_put(CYW43_WL_GPIO_LED_PIN, led_on);
                    last_led_toggle = now;
                }
            }
        }

        // --- Status report every 3 seconds ---
        if (now - last_status_print >= 3000) {
            last_status_print = now;
            printf("[STATUS] t=%lu BLE:%s USB:%s notifs=%lu\n",
                   (unsigned long)now,
                   ble_hid_client_connected() ? "READY" : "scanning",
                   tud_ready() ? "OK" : "wait",
                   (unsigned long)ble_hid_client_notification_count());
            fflush(stdout);
        }

        tight_loop_contents();
    }

    // Never reached
    cyw43_arch_deinit();
    return 0;
}
